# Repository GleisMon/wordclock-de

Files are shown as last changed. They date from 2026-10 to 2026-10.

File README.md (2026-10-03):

# Wortuhr – Firmware für die deutsche Word Clock (ESP8266)

Firmware für eine 3D-gedruckte Wortuhr mit deutschem Ziffernblatt (12 × 11 Buchstaben, 132 WS2812B-LEDs),
gesteuert von einem **Lolin NodeMCU v3 (ESP8266)**, der unsichtbar im Ständer sitzt.

[Русская версия](README.ru.md)

- Einrichtung ohne Programmieren: WLAN per Handy, Zeit per Internet (NTP), Sommerzeit automatisch
- Zufällige Farben – bei jeder neuen Anzeige bekommt **jedes** Wort eine neue Farbe
- Helligkeit, Nachtmodus, „MINUTEN“ ein/aus, Herz zur vollen Stunde (optional)
- Einstellungsseite im Browser: **http://wortuhr.local** (Deutsch / Русский / English)
- Updates über WLAN direkt aus GitHub Releases, signiert; Rettungsmodus falls etwas schiefgeht
- Strombegrenzung für ein 2-A-USB-Netzteil
- Optional: kleiner Bildschirm (0,91" OLED) im Ständer – zeigt Adresse, WLAN-Einrichtung, Fehler,
  Update-Fortschritt und auf Wunsch die genaue Uhrzeit

## Erste Inbetriebnahme

1. Uhr mit dem USB-C-Netzteil verbinden. Die vier Eck-LEDs pulsieren **blau**: die Uhr wartet auf WLAN-Daten.
2. Mit dem Handy das WLAN **„Wortuhr-Setup“** wählen. Die Einrichtungsseite öffnet sich (sonst `http://192.168.4.1`).
3. „Configure WiFi“ → eigenes WLAN wählen, Passwort eingeben, speichern.
4. Ecken pulsieren **orange**, bis die Uhrzeit aus dem Internet geholt ist – dann erscheint die Zeit.

Einstellungen danach im Browser unter **http://wortuhr.local** (oder über die IP-Adresse aus dem Router).

| Ecken pulsieren | Bedeutung |
|---|---|
| blau | Einrichtungs-WLAN „Wortuhr-Setup“ ist offen |
| orange | verbindet sich / wartet auf die Uhrzeit |
| rot | Rettungsmodus (siehe unten) |

Ist das WLAN 10 Minuten weg (z. B. neuer Router), öffnet die Uhr wieder „Wortuhr-Setup“ und zeigt
weiter die Zeit an.

## Wie die Zeit angezeigt wird

| Minute | Anzeige (Standard) |
|---|---|
| :00 | ES IST DREI UHR (bei 1 Uhr: ES IST EIN UHR) |
| :05 / :10 | ES IST FÜNF / ZEHN MINUTEN NACH DREI |
| :15 | ES IST VIERTEL NACH DREI |
| :20 | ES IST ZWANZIG MINUTEN NACH DREI *(oder: ZEHN VOR HALB VIER)* |
| :25 | ES IST FÜNF VOR HALB VIER |
| :30 | ES IST HALB VIER |
| :35 | ES IST FÜNF NACH HALB VIER |
| :40 | ES IST ZWANZIG MINUTEN VOR VIER *(oder: ZEHN NACH HALB VIER)* |
| :45 | ES IST VIERTEL VOR VIER |
| :50 / :55 | ES IST ZEHN / FÜNF MINUTEN VOR VIER |

„MINUTEN“ lässt sich abschalten, die Varianten für :20 / :40 und „ES IST nur zur vollen und halben Stunde“
stehen unter *Erweiterte Einstellungen*.

## Bildschirm im Ständer (optional)

Wird beim Start automatisch erkannt – ohne Bildschirm läuft dieselbe Firmware unverändert.

| Situation | Anzeige |
|---|---|
| WLAN-Einrichtung | „WLAN einrichten: Wortuhr-Setup · 192.168.4.1“ (solange das Portal offen ist) |
| nach dem Einschalten | IP-Adresse, wortuhr.local und Uhrzeit – für die eingestellte Zeit (Standard 5 min, 0 = aus, „immer“) |
| danach | aus (Standard) oder **genaue Uhrzeit** (gedimmt, wandert auf einer Acht-Bahn gegen Einbrennen: 1 Schritt/min, 1 Runde/h) |
| Fehler | „Kein WLAN“, „Keine Uhrzeit“, „Update fehlgeschlagen“ |
| Update | Fortschrittsbalken mit Prozent (GitHub, Browser-Upload, Arduino-OTA) |
| Nachtmodus | aus (Fehler werden gedimmt angezeigt) |

Einstellungen: *Bildschirm im Ständer* auf der Einstellungsseite (erscheint nur mit Bildschirm), dort auch „Bildschirm drehen“.

## Updates

Die Uhr schaut einmal am Tag nach, ob es auf GitHub eine neue Version gibt, und zeigt sie auf der
Einstellungsseite an („Update installieren“). Auf Wunsch installiert sie Updates nachts um 3 Uhr selbst.
Es werden nur Firmware-Dateien angenommen, die mit dem Schlüssel dieses Projekts signiert sind.

**Rettungsmodus:** Startet die Uhr dreimal hintereinander innerhalb von 30 Sekunden neu, öffnet sie das
WLAN **„Wortuhr-Rescue“** (Ecken rot). Dort unter `http://192.168.4.1/update` die Datei `wortuhr-de.bin`
aus dem neuesten [Release](https://github.com/GleisMon/wordclock-de/releases) hochladen.

## Hardware

| Teil | Hinweis |
|---|---|
| Gehäuse + Front | [`hardware/clock-case`](hardware/clock-case) – deutsches Layout von KS, Remix der Word Clock von johniak |
| Ständer | [`hardware/stand`](hardware/stand) – versteckt den NodeMCU, wird mit den zwei unteren Gehäuseschrauben befestigt (v4 ohne, v5 mit Bildschirmfenster) |
| Bildschirm (optional) | SSD1306 0,91" 128×32, I2C 0x3C: **SDA → D2 (GPIO4), SCL → D1 (GPIO5)**, VCC 3,3 V, GND |
| Controller | Lolin NodeMCU v3 (ESP8266, 4 MB Flash) |
| LEDs | WS2812B-Streifen 74 LED/m, 11 Reihen × 12, Schlangenlinie, Anfang unten rechts |
| Strom | 5 V / 2 A USB-Netzteil über USB-C-Einbaubuchse (nur Strom) |

Verdrahtung: LED **DIN → D4 (GPIO2)** über einen Widerstand (z. B. 330 Ω), LED 5 V und NodeMCU **VIN** direkt an
5 V der USB-C-Buchse, GND gemeinsam. Hinweis: Eine 2-polige USB-C-Buchse braucht 5,1-kΩ-CC-Widerstände,
sonst liefern C-auf-C-Netzteile keine Spannung.

## Entwicklung

Arduino-CLI, Board **NodeMCU 1.0 (ESP-12E)**, Flash-Layout **4MB (FS:1MB OTA:~1019KB)**:

```bash
arduino-cli core install esp8266:esp8266@3.1.2
arduino-cli lib install "NeoPixelBus by Makuna@2.8.4" "WiFiManager@2.0.17" "ArduinoJson@7.4.3" "U8g2@2.36.19"
arduino-cli compile --fqbn esp8266:esp8266:nodemcuv2:eesz=4M1M,xtal=160,ip=lm2f,ssl=all --output-dir build firmware/Wortuhr
```

- **Signatur:** `firmware/Wortuhr/public.key` ist eingebaut; die Firmware akzeptiert per OTA/Upload nur
  Images, die mit dem passenden `private.key` signiert sind. Der private Schlüssel liegt **nicht** im Repo
  (lokal neben dem Sketch, in CI als Secret `SIGNING_KEY`). Per USB lässt sich jede Firmware flashen.
- **Release:** `FW_VERSION` in `firmware/Wortuhr/version.h` erhöhen, committen, Tag `vX.Y.Z` pushen –
  GitHub Actions baut, signiert und veröffentlicht `wortuhr-de.bin` + `version.json`.
- **Serielle Konsole** (115200 Bd): `dump` gibt alle 144 Sätze für die aktuellen Einstellungen aus, `info` den Status.
- **Zertifikate:** Die Root-CAs für den GitHub-Download stehen in `certs.h`; erneuern mit `tools/make_certs.py`.

## Herkunft und Lizenzen

- **Word Clock** (Original, Gehäuse und Idee): [johniak – Word Clock auf MakerWorld](https://makerworld.com/en/models/686196),
  Code: [github.com/johniak/word-clock](https://github.com/johniak/word-clock)
- **Deutsche Version** (Gehäuse/Front mit deutschem Layout): [KS – Word Clock (German version) auf MakerWorld](https://makerworld.com/en/models/1222379),
  Lizenz **CC BY-SA 4.0** – die Datei in `hardware/clock-case` ist unverändert übernommen.
- **Ständer:** eigene Konstruktion, angelehnt an „Stand for Word Clock“ von **LarsIversen** (MakerWorld, CC BY-NC-SA) –
  daher ebenfalls **CC BY-NC-SA 4.0**.
- **Firmware** (`firmware/`, `tools/`): neu geschrieben, **MIT** (siehe [LICENSE](LICENSE)). Übernommen wurde nur
  die Buchstaben- und LED-Belegung der deutschen Front.

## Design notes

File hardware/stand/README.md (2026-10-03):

# Ständer mit verstecktem NodeMCU

> **Welche Datei?** Die Word Clock gibt es in zwei Größen. **v9** passt zur großen Version
> (`hardware/clock-case/word_clock_GERMAN_60LED_per_meter.3mf`, = 74-LED-Modell × 1,2333): Uhr 230,78 mm breit (Ständer genauso
> lang, bündig), Schraubenlöcher 213,5 mm auseinander, 8,63 mm über der Unterkante und vom Seitenrand; Uhrendicke gemessen 17,2 mm.
> **v4/v5** passen zur kleinen Version aus `hardware/clock-case` (74 LED/m): 187 mm breit, 15 mm dick, Löcher 173 mm.
> Vor dem Druck die eigene Uhr nachmessen und zuerst `wortuhr-stand_v9_testslice.stl` (22-mm-Endstück) anprobieren.

- `wortuhr-stand_v9.stl` / `.step` – große Uhr (60 LED/m), mit OLED-Fenster wie v5; Länge 230,78 mm (bündig mit der Uhr). USB-C-Ausschnitt rechteckig
  13,9 × 5,9 mm, symmetrisch (Buchse 14 × 5,2, in der Breite stramm; die runde 5,3-mm-Variante passte nicht), 2,5 mm tiefer als in v7 und weiter hinten, ganz über dem Schraubenblock (keine Aussparung im Block → keine
  Überhänge beim Druck mit dem Bildschirm nach unten); Übergang Boden → Auflage als gerade Fase 2 mm auf 6 mm; OLED-Tasche mit 2-mm-Rand innen
  (45°-Übergang in die Wand), Einstecktiefe 3,7 mm. Die STLs liegen für den Druck **Bildschirmseite nach unten**
  (schräge Rückwand auf dem Bett).
- `wortuhr-stand_v9_testslice.stl` – rechtes Endstück (Schraubenblock, USB-C-Buchse) zum Anprobieren.

- `wortuhr-stand_v5.stl` / `.step` – wie v4, zusätzlich Fenster für einen 0,91"-OLED (SSD1306 128×32) oben in der
  schrägen Rückwand: Tasche 39 × 12,2 × 1,7 mm von innen, Fenster 24 × 8,2 mm mit Fase 0,5 mm, 0,8 mm Haut,
  Wand überall 2,5 mm (kein Rahmen; das Modul steht innen ~0,8 mm über). Maße aus dem Reflex-Deckel.
  Modul mit einem Tropfen Kleber oder Klebeband sichern. Außerdem: keine Fasen an den Stirnkanten, die an der
  Uhr anliegen (Rückseite, Auflage, Vorderkante bündig mit der Front), 6-mm-Fase an der oberen Innenkante der
  Schraubenblöcke.
- `wortuhr-stand_v4.stl` – druckfertig, liegt so auf dem Druckbett, wie er auf dem Tisch steht (keine Stützen nötig)
- `wortuhr-stand_v4.step` – zum Weiterbearbeiten
- `fusion-scripts/` – Fusion-360-Skripte, die das Modell erzeugen (`v4_build.py`, `v5_chamfer.py`, `v5_screen.py`) und die Passung prüfen (`chk_v4.py`, `chk_v5.py`)

**Maße (v4/v5):** 194 × 50 × 56 mm; v9: 230,8 × 53 × 56 mm. Die Fusion-Skripte erzeugen v9 (Konstanten oben in `v4_build.py`), Uhr 10° nach hinten geneigt, Vorderseite bündig mit der Front der Uhr.

**Befestigung:** zwei Schrauben Ø 3,7 × 40 mm (Kopf Ø 5,9 × 2 mm) durch den Ständer in die beiden unteren
Löcher der Uhr. Klemmlänge 30 mm (Rückseite der Uhr bis Senkungsboden), Senkung Ø 6,6 × 2,5 mm,
Durchgang Ø 4,2 mm → die Schraube greift ca. 10 mm in den Dom der Uhr (verfügbar: 13 mm).
Unterlegscheibe M3 empfohlen.

**Innenraum:** NodeMCU v3 (58 × 31 mm) passt stehend hinter die Uhr. Rechts (von vorne) ein Ausschnitt
13,9 × 5,3 mm (abgerundet) für eine USB-C-Einbaubuchse 13,7 × 5,1 mm, Wand dort 1,5 mm für die Rastnasen.

Druck: PETG, 0,2 mm, Fasen 45° statt Rundungen.

**Lizenz:** CC BY-NC-SA 4.0 – angelehnt an „Stand for Word Clock“ von **LarsIversen** (MakerWorld, CC BY-NC-SA).
https://creativecommons.org/licenses/by-nc-sa/4.0/

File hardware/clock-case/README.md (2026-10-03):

# Gehäuse und Front – deutsches Layout

`word_clock_GERMAN_74LED_per_meter.3mf` – unverändert übernommen.

- **Word Clock (German version)** von **KS**: https://makerworld.com/en/models/1222379
- Remix von **Word Clock** von **johniak**: https://makerworld.com/en/models/686196
- Lizenz: **CC BY-SA 4.0** (Namensnennung, Weitergabe unter gleichen Bedingungen)
  https://creativecommons.org/licenses/by-sa/4.0/

Inhalt: Gehäuse (187 × 179 × 12 mm) mit transparenter und weißer Frontschicht, Rückplatte 3 mm
(Platte 2 im 3MF). Aufbauanleitung: https://github.com/johniak/word-clock/blob/main/docs/device_build.md

Zwei Größen, gleiche Lizenz (CC BY-SA 4.0, KS):
- `word_clock_GERMAN_74LED_per_meter.3mf` – 187 mm breit (74-LED/m-Streifen)
- `word_clock_GERMAN_60LED_per_meter.3mf` – dasselbe Modell × 1,2333 = 230,8 mm breit (60-LED/m-Streifen); dafür ist der Ständer v9.

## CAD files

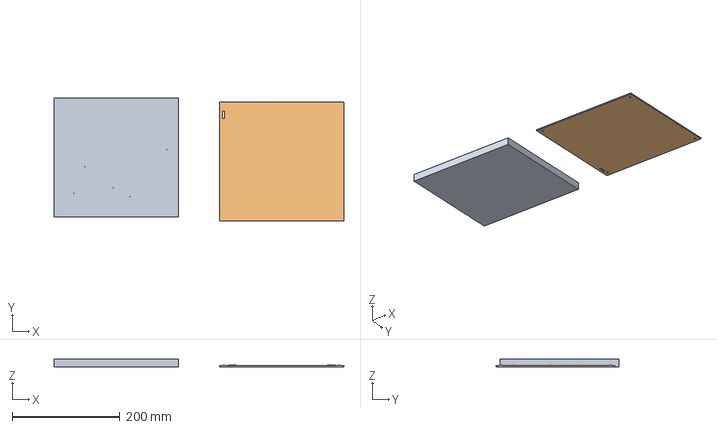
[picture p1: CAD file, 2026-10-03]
hardware/clock-case/word_clock_GERMAN_60LED_per_meter.3mf
537.3 x 227.8 x 14.8 mm
German box
obj_2_Body1.stl

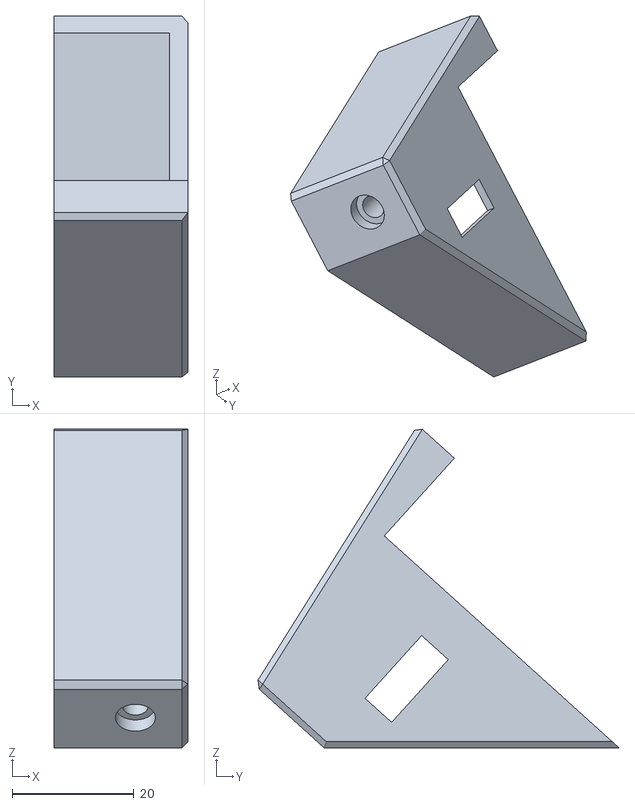
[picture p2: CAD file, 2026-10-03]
hardware/stand/wortuhr-stand_v9_testslice.stl
22.0 x 59.4 x 52.4

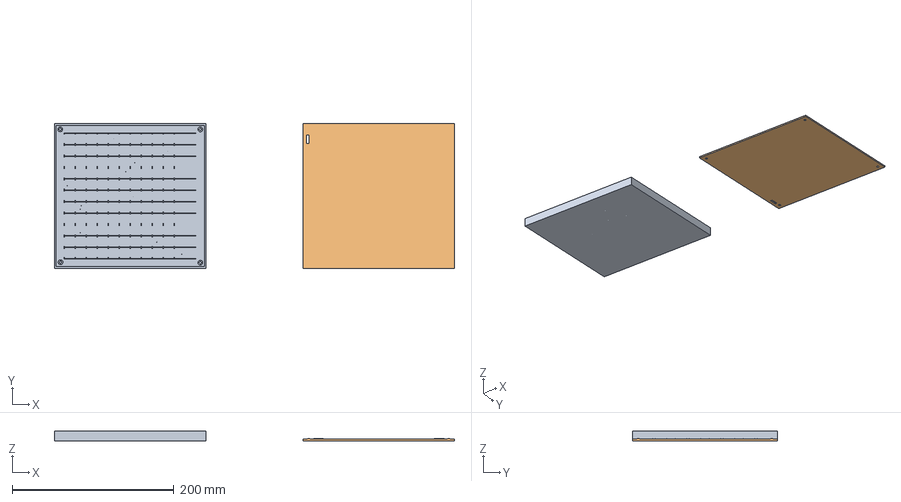
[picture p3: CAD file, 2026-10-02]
hardware/clock-case/word_clock_GERMAN_74LED_per_meter.3mf
494.3 x 178.6 x 12.0 mm
German box
obj_2_Body1.stl

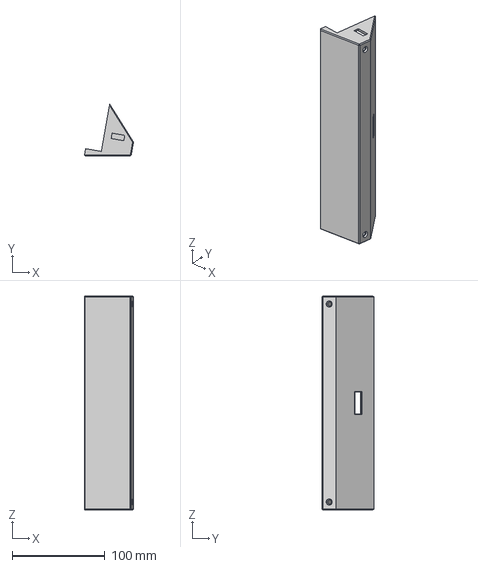
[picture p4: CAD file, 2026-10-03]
hardware/stand/wortuhr-stand_v9.step
53.0 x 56.2 x 230.8 mm

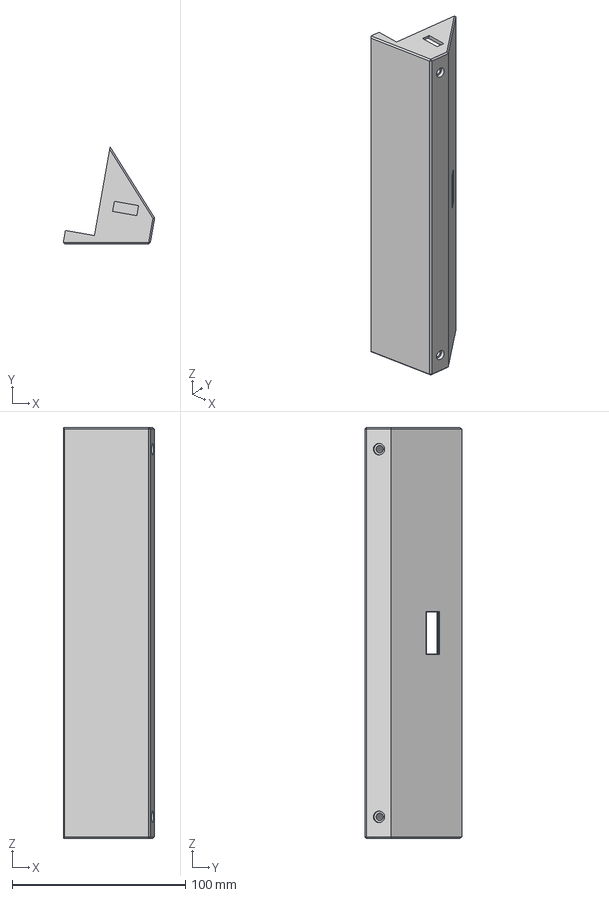
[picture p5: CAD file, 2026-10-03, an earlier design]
hardware/stand/wortuhr-stand_v8.step
52.8 x 56.2 x 237.0 mm

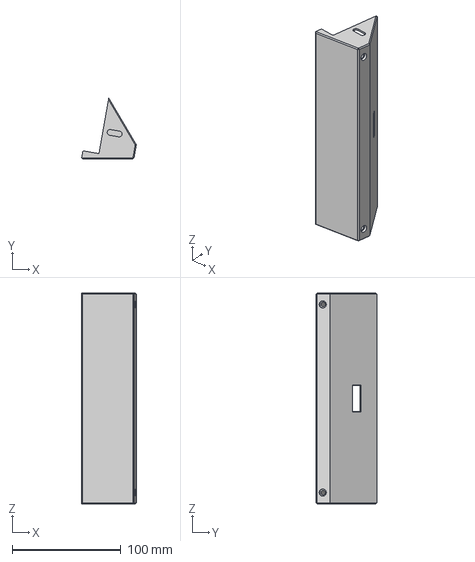
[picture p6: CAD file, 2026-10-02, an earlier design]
hardware/stand/wortuhr-stand_v5.step
50.4 x 56.2 x 194.1 mm

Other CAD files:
hardware/stand/wortuhr-stand_v6.step
hardware/stand/wortuhr-stand_v4.step
hardware/stand/wortuhr-stand_v4.stl
hardware/stand/wortuhr-stand_v5.stl
hardware/stand/wortuhr-stand_v9.stl

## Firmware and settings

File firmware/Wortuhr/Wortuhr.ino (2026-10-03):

// Wortuhr — German word clock firmware for ESP8266 (Lolin NodeMCU v3)
// https://github.com/GleisMon/wordclock-de
//
// LED data: D4 (GPIO2) through a series resistor. 132 x WS2812B, 12 x 11 grid.
#include <ESP8266WiFi.h>
#include <ESP8266WebServer.h>
#include <ESP8266HTTPUpdateServer.h>
#include <ESP8266mDNS.h>
#include <ArduinoOTA.h>
#include <WiFiManager.h>
#include <LittleFS.h>
#include <coredecls.h>
#include <time.h>

#include "version.h"
#include "grammar.h"
#include "display.h"
#include "settings.h"
#include "gh_update.h"
#include "webui.h"
#include "screen.h"

static const char *HOSTNAME = "wortuhr";
static const char *AP_SETUP = "Wortuhr-Setup";
static const char *AP_RESCUE = "Wortuhr-Rescue";
static const uint32_t PALETTE[] = {0xFF0000, 0x00FF00, 0x0000FF, 0xFFFF00, 0xFF00FF, 0x00FFFF, 0xFFFFFF, 0xFF7A00};
static const uint8_t PALETTE_N = sizeof(PALETTE) / sizeof(PALETTE[0]);

Display display;
Settings cfg;
GhUpdate gh;
ESP8266WebServer server(80);
ESP8266HTTPUpdateServer httpUpdater;
WiFiManager wm;
Screen screen;

enum Anim { A_NONE, A_HEART, A_TEST } anim = A_NONE;  // before the first function (Arduino prototypes)
uint32_t animStart = 0;

// ---------- texts for the optional stand display ----------
enum Txt { S_SETUP, S_WEB, S_NOWIFI, S_RETRY, S_NOTIME, S_RESCUE, S_UPDFAIL, S_UPDAVAIL, S_CONNECT, S_UPLOAD, S_RESTART, S_COUNT };
// one '\0'-separated block per language in flash (string constants would otherwise sit in RAM)
static const char TXT_DE[] PROGMEM =
  "WLAN einrichten:\0Einstellungen im Browser:\0Kein WLAN\0verbinde neu ...\0Keine Uhrzeit\0Rettungsmodus - WLAN:\0"
  "Update fehlgeschlagen\0Update verfügbar: \0verbinde ...\0Firmware-Upload\0Neustart ...";
static const char TXT_EN[] PROGMEM =
  "Set up WiFi:\0Settings in the browser:\0No WiFi\0reconnecting ...\0No time\0Rescue mode - WiFi:\0"
  "Update failed\0Update available: \0connecting ...\0Firmware upload\0restarting ...";
static const char TXT_RU[] PROGMEM =
  "Настройка Wi-Fi:\0Настройки в браузере:\0Нет Wi-Fi\0переподключение ...\0Нет времени\0Аварийный режим, Wi-Fi:\0"
  "Обновление не удалось\0Есть обновление: \0подключение ...\0Загрузка прошивки\0перезагрузка ...";
String T(Txt k) {
  const char *p = cfg.lang == "en" ? TXT_EN : cfg.lang == "ru" ? TXT_RU : TXT_DE;
  for (uint8_t i = 0; i < k; i++) p += strlen_P(p) + 1;
  return String(FPSTR(p));
}

bool rescue = false, routesReady = false, servicesUp = false, portalOn = false, otaReady = false;
uint32_t portalSince = 0, staRetryAt = 0, lostSince = 0, saveAt = 0, nextCheckAt = 0, rebootAt = 0, lastAutoTry = 0;
bool pendingCheck = false, pendingInstall = false, forceRecolor = true;
uint32_t lastMask = 0, lastTick = 0;
int lastHeartHour = -1;
uint32_t wordColor[W_COUNT];
RgbColor wordFrame[NUM_LEDS], frame[NUM_LEDS];


// ---------- rescue mode: 3 boots in a row that die within 30 s ----------
struct RtcBoot { uint32_t magic, count; };
static const uint32_t RTC_MAGIC = 0x57C10C01;
bool bootCounterCleared = false;

uint32_t bumpBootCounter() {
  RtcBoot b;
  ESP.rtcUserMemoryRead(0, (uint32_t *)&b, sizeof(b));
  if (b.magic != RTC_MAGIC) b = {RTC_MAGIC, 0};
  b.count++;
  ESP.rtcUserMemoryWrite(0, (uint32_t *)&b, sizeof(b));
  return b.count;
}
void clearBootCounter() {
  RtcBoot b = {RTC_MAGIC, 0};
  ESP.rtcUserMemoryWrite(0, (uint32_t *)&b, sizeof(b));
}

// ---------- update boot: the firmware download needs ~30 KB heap, so it runs in a reboot
// without web server / mDNS / OTA / portal. Request and result travel through RTC memory.
struct RtcText { uint32_t magic; char text[64]; };
static const uint32_t RTC_UPD_REQ = 0x55504451, RTC_UPD_RES = 0x55504452;
static const uint32_t RTC_OFS_REQ = 2, RTC_OFS_RES = 2 + sizeof(RtcText) / 4, RTC_OFS_CHK = 2 + 2 * sizeof(RtcText) / 4;
static const uint32_t RTC_CHECKING = 0x43484B31;  // set while a version check runs; survives a crash
bool autoCheckBlocked = false;

void rtcPut(uint32_t ofs, uint32_t magic, const String &s) {
  RtcText r = {magic, {0}};
  strncpy(r.text, s.c_str(), sizeof(r.text) - 1);
  ESP.rtcUserMemoryWrite(ofs, (uint32_t *)&r, sizeof(r));
}
bool rtcTake(uint32_t ofs, uint32_t magic, String &out) {
  RtcText r;
  ESP.rtcUserMemoryRead(ofs, (uint32_t *)&r, sizeof(r));
  if (r.magic != magic) return false;
  r.text[sizeof(r.text) - 1] = 0;
  out = r.text;
  r.magic = 0;
  ESP.rtcUserMemoryWrite(ofs, (uint32_t *)&r, sizeof(r));
  return true;
}

// ---------- helpers ----------
RgbColor rgb(uint32_t c) { return RgbColor((c >> 16) & 0xFF, (c >> 8) & 0xFF, c & 0xFF); }

uint8_t levelFromPct(uint8_t pct) {  // perceptual curve
  if (pct == 0) return 0;
  uint16_t v = (uint32_t)pct * pct * 255 / 10000;
  return v < 1 ? 1 : v;
}

bool inNight(int minuteOfDay) {
  if (!cfg.nightOn || cfg.nightFrom == cfg.nightTo) return false;
  return cfg.nightFrom < cfg.nightTo ? (minuteOfDay >= cfg.nightFrom && minuteOfDay < cfg.nightTo)
                                     : (minuteOfDay >= cfg.nightFrom || minuteOfDay < cfg.nightTo);
}

void fillCorners(RgbColor c) {
  for (uint16_t i = 0; i < NUM_LEDS; i++) frame[i] = RgbColor(0);
  frame[ledIndex(0, 0)] = frame[ledIndex(0, GRID_W - 1)] = frame[ledIndex(GRID_H - 1, 0)] = frame[ledIndex(GRID_H - 1, GRID_W - 1)] = c;
}

void statusPulse(uint32_t color) {  // corners breathe: blue = setup portal, orange = waiting for time, red = rescue
  float k = 0.15f + 0.85f * (0.5f + 0.5f * sinf(millis() / 600.0f));
  RgbColor c = rgb(color);
  fillCorners(RgbColor(c.R * k, c.G * k, c.B * k));
  display.setLevel(90);
  display.setFrame(frame);
}

void assignColors(const Phrase &p) {
  uint8_t idx[PALETTE_N];
  for (uint8_t i = 0; i < PALETTE_N; i++) idx[i] = i;
  for (uint8_t attempt = 0; attempt < 16; attempt++) {  // every word gets a new colour, all different
    for (int8_t i = PALETTE_N - 1; i > 0; i--) { uint8_t j = random(i + 1); uint8_t t = idx[i]; idx[i] = idx[j]; idx[j] = t; }
    bool ok = true;
    for (uint8_t i = 0; i < p.n; i++) if (wordColor[p.w[i]] == PALETTE[idx[i]]) { ok = false; break; }
    if (ok) break;
  }
  for (uint8_t i = 0; i < p.n; i++) wordColor[p.w[i]] = cfg.colorMode == 1 ? cfg.color : PALETTE[idx[i % PALETTE_N]];
}

void buildWordFrame(const Phrase &p) {
  for (uint16_t i = 0; i < NUM_LEDS; i++) wordFrame[i] = RgbColor(0);
  for (uint8_t i = 0; i < p.n; i++) {
    const WordPos &w = WORDS[p.w[i]];
    for (uint8_t c = 0; c < w.len; c++) wordFrame[ledIndex(w.row, w.col + c)] = rgb(wordColor[p.w[i]]);
  }
}

// ---------- animations ----------
static const char HEART[GRID_H][GRID_W + 1] = {
  "..XX....XX..", ".XXXX..XXXX.", "XXXXXXXXXXXX", "XXXXXXXXXXXX", "XXXXXXXXXXXX", ".XXXXXXXXXX.",
  "..XXXXXXXX..", "...XXXXXX...", "....XXXX....", ".....XX.....", "............"};

void startAnim(Anim a) { anim = a; animStart = millis(); }

bool renderAnim() {
  uint32_t t = millis() - animStart;
  if (anim == A_HEART) {
    if (t > 4000) return false;
    float ph = fmodf(t / 900.0f, 1.0f);  // lub-dub
    float beat = 0.35f + 0.65f * max(expf(-30 * ph * ph), 0.7f * expf(-30 * (ph - 0.28f) * (ph - 0.28f)));
    for (uint8_t r = 0; r < GRID_H; r++)
      for (uint8_t c = 0; c < GRID_W; c++)
        frame[ledIndex(r, c)] = HEART[r][c] == 'X' ? RgbColor(255 * beat, 0, 20 * beat) : RgbColor(0);
  } else if (anim == A_TEST) {
    if (t > 6000) return false;
    static const uint32_t seq[] = {0xFF0000, 0x00FF00, 0x0000FF, 0xFFFFFF};
    RgbColor c = rgb(seq[(t / 1500) % 4]);
    for (uint16_t i = 0; i < NUM_LEDS; i++) frame[i] = c;
  } else return false;
  display.setFrame(frame);
  return true;
}

// ---------- the clock ----------
void tick() {
  time_t now = time(nullptr);
  if (now < 1700000000) {  // no valid time yet
    statusPulse(portalOn ? 0x0040FF : 0xFF8000);
    return;
  }
  struct tm t;
  localtime_r(&now, &t);
  bool night = inNight(t.tm_hour * 60 + t.tm_min);
  display.setLevel(levelFromPct(night ? cfg.nightBrightness : cfg.brightness));

  if (lastHeartHour < 0) lastHeartHour = t.tm_hour;
  if (cfg.heart && t.tm_min == 0 && t.tm_hour != lastHeartHour && anim == A_NONE) {
    lastHeartHour = t.tm_hour;
    if (!(night && cfg.nightBrightness == 0)) startAnim(A_HEART);
  }
  if (anim != A_NONE) {
    if (renderAnim()) return;
    anim = A_NONE;
    display.setTarget(wordFrame, cfg.fade ? 600 : 0);
  }

  GrammarOpts o;
  o.minuten = cfg.minuten; o.v20 = cfg.v20; o.v40 = cfg.v40; o.esIstAlways = cfg.esIstAlways;
  Phrase p = buildPhrase(t.tm_hour, t.tm_min, o);
  if (p.mask != lastMask || forceRecolor) {
    assignColors(p);
    buildWordFrame(p);
    display.setTarget(wordFrame, cfg.fade ? 900 : 0);
    lastMask = p.mask;
    forceRecolor = false;
  }
}

// ---------- stand display: what to show, most important first ----------
void screenLoop() {
  if (!screen.present) return;
  // screens that can stay up for long drift on the burn-in orbit (see Screen::orbit)
  if (rescue) { screen.text(T(S_RESCUE), AP_RESCUE, "192.168.4.1/update", 160, true); return; }
  if (portalOn) { screen.text(T(S_SETUP), AP_SETUP, "192.168.4.1", 160, true); return; }
  time_t now = time(nullptr);
  bool valid = now > 1700000000, up = WiFi.status() == WL_CONNECTED;
  struct tm t = {};
  if (valid) localtime_r(&now, &t);
  bool night = valid && inNight(t.tm_hour * 60 + t.tm_min);
  if (!up && lostSince && millis() - lostSince > 20000) { screen.text(T(S_NOWIFI), WiFi.SSID(), T(S_RETRY), night ? 12 : 160, true); return; }
  if (up && !valid && millis() > 60000) { screen.text(T(S_NOTIME), "NTP", cfg.ntp, night ? 12 : 160, true); return; }
  bool always = cfg.oledMin == 255;
  bool infoTime = always || millis() < cfg.oledMin * 60000UL;
  if (valid && t.tm_min == 0 && t.tm_sec < 2 && (always || cfg.oledAfter == 1)) { screen.off(); return; }  // 2 s rest each hour
  if (infoTime && !night) {
    String foot = "wortuhr.local";
    if (gh.error.startsWith("Update")) foot = T(S_UPDFAIL);
    else if (gh.available()) foot = T(S_UPDAVAIL) + gh.latest;
    else if (valid) { char b[8]; snprintf(b, sizeof(b), "  %02d:%02d", t.tm_hour, t.tm_min); foot += b; }
    screen.text(T(S_WEB), up ? WiFi.localIP().toString() : T(S_CONNECT), foot, 160, always);
    return;
  }
  if (cfg.oledAfter == 1 && valid && !night) { screen.clock(t.tm_hour, t.tm_min); return; }
  screen.off();
}

// ---------- web ----------
void applyConfig(const Settings &old) {
  screen.setFlip(cfg.oledFlip);
  screen.setLang(cfg.lang);
  display.setLimit(cfg.limitMa);
  if (old.tz != cfg.tz || old.ntp != cfg.ntp) configTime(cfg.tz.c_str(), cfg.ntp.c_str(), "pool.ntp.org");
  if (old.colorMode != cfg.colorMode || (cfg.colorMode == 1 && old.color != cfg.color)) forceRecolor = true;
}

void handleState() {
  JsonDocument doc;
  cfg.toJson(doc["cfg"].to<JsonObject>());
  JsonObject st = doc["st"].to<JsonObject>();
  time_t now = time(nullptr);
  st["synced"] = now > 1700000000;
  if (now > 1700000000) {
    struct tm t; localtime_r(&now, &t);
    char b[24];
    strftime(b, sizeof(b), "%H:%M", &t); st["time"] = b;
    strftime(b, sizeof(b), "%d.%m.%Y", &t); st["date"] = b;
  }
  st["ver"] = FW_VERSION;
  st["ip"] = WiFi.localIP().toString();
  st["ssid"] = WiFi.SSID();
  st["rssi"] = WiFi.RSSI();
  st["heap"] = ESP.getFreeHeap();
  st["uptime"] = millis() / 1000;
  st["mA"] = display.lastMa();
  st["checked"] = gh.checked;
  st["latest"] = gh.latest;
  st["updAvail"] = gh.available();
  st["updErr"] = gh.error;
  st["updHeap"] = gh.heapAtConnect;
  st["updBlock"] = gh.blockAtConnect;
  st["oled"] = screen.present;
  String out;
  serializeJson(doc, out);
  server.send(200, "application/json", out);
}

void handleConfig() {
  JsonDocument doc;
  if (deserializeJson(doc, server.arg("plain"))) { server.send(400, "text/plain", "bad json"); return; }
  Settings old = cfg;
  cfg.fromJson(doc.as<JsonObjectConst>());
  applyConfig(old);
  saveAt = millis() + 3000;  // sliders: write flash once they stop moving
  server.send(200, "application/json", "{\"ok\":true}");
}

void handleAction() {
  String a = server.arg("a");
  if (a == "reroll") forceRecolor = true;
  else if (a == "heartnow") startAnim(A_HEART);
  else if (a == "test") startAnim(A_TEST);
  else if (a == "check") pendingCheck = true;
  else if (a == "install") pendingInstall = true;
  else if (a == "reboot") rebootAt = millis() + 500;
  else if (a == "wifireset") { wm.resetSettings(); rebootAt = millis() + 500; }
  else if (a == "factory") { LittleFS.remove("/config.json"); wm.resetSettings(); rebootAt = millis() + 500; }
  else { server.send(400, "text/plain", "unknown action"); return; }
  server.send(200, "application/json", "{\"ok\":true}");
}

void setupRoutes() {
  if (routesReady) return;
  if (rescue) {
    server.on("/", HTTP_GET, [] { server.send_P(200, "text/html", RESCUE_HTML); });
    server.on("/normal", HTTP_GET, [] { clearBootCounter(); server.send(200, "text/plain", "Neustart..."); rebootAt = millis() + 500; });
  } else {
    server.on("/", HTTP_GET, [] { server.send_P(200, "text/html", INDEX_HTML); });
    server.on("/api/state", HTTP_GET, handleState);
    server.on("/api/config", HTTP_POST, handleConfig);
    server.on("/api/action", HTTP_POST, handleAction);
  }
  httpUpdater.setup(&server, "/update");  // Updater only accepts images signed with our key
  server.onNotFound([] { server.sendHeader("Location", "/"); server.send(302); });
  routesReady = true;
}

void startServices() {
  setupRoutes();
  server.begin();
  MDNS.begin(HOSTNAME);
  MDNS.addService("http", "tcp", 80);
  if (!otaReady) {
    ArduinoOTA.setHostname(HOSTNAME);
    ArduinoOTA.onProgress([](unsigned int done, unsigned int total) { uploadProgress(done, total); });
    ArduinoOTA.begin();
    otaReady = true;
  }
  servicesUp = true;
  if (!nextCheckAt) nextCheckAt = millis() + 60000;
  Serial.printf("[net] %s  http://%s.local  ip %s\n", WiFi.SSID().c_str(), HOSTNAME, WiFi.localIP().toString().c_str());
}

void stopServices() {
  server.stop();
  MDNS.end();
  servicesUp = false;
}

void openPortal() {
  if (servicesUp) stopServices();
  wm.startConfigPortal(rescue ? AP_RESCUE : AP_SETUP);
  portalOn = true;
  portalSince = millis();
  Serial.println("[net] setup portal open");
}

// ---------- WiFi state machine ----------
void wifiLoop() {
  if (portalOn) wm.process();
  bool up = WiFi.status() == WL_CONNECTED;
  if (up) {
    lostSince = 0; staRetryAt = 0;
    if (portalOn) { wm.stopConfigPortal(); portalOn = false; }
    if (!servicesUp) startServices();
    return;
  }
  if (!lostSince) lostSince = millis();
  if (portalOn) {
    // saved network may be back: every 5 min (nobody on the portal) try it for 30 s
    if (millis() - portalSince > 300000 && wm.getWiFiIsSaved() && WiFi.softAPgetStationNum() == 0) {
      wm.stopConfigPortal(); portalOn = false;
      WiFi.mode(WIFI_STA); WiFi.begin();
      staRetryAt = millis();
    }
  } else if (staRetryAt && millis() - staRetryAt > 30000) {
    staRetryAt = 0; openPortal();
  } else if (!staRetryAt && millis() - lostSince > 600000) {
    openPortal();  // lost for 10 min (new router?) -> offer setup again, keep showing time
  }
}

void installUpdate() {  // normal mode: hand over to the update boot
  if (!gh.available()) return;
  MDNS.end();
  String url;
  bool ok = gh.assetUrl(url);  // follow github.com's redirects here, the update boot only talks to the CDN
  MDNS.begin(HOSTNAME);
  MDNS.addService("http", "tcp", 80);
  if (!ok) { Serial.printf("[upd] resolve failed: %s\n", gh.error.c_str()); return; }
  File f = LittleFS.open("/upd.url", "w");
  if (!f) { gh.error = "fs"; return; }
  f.print(url);
  f.close();
  Serial.printf("[upd] rebooting to install %s\n", gh.latest.c_str());
  screen.text("Update " + gh.latest, T(S_RESTART), "");
  if (saveAt) cfg.save();
  rtcPut(RTC_OFS_REQ, RTC_UPD_REQ, gh.latest);
  delay(50);
  ESP.restart();
}

void ledProgress(int done, int total) {
  fillCorners(RgbColor(0));
  for (uint16_t i = 0; i < (uint32_t)NUM_LEDS * done / max(total, 1); i++) frame[i] = RgbColor(0, 0, 255);
  display.setLevel(60); display.setFrame(frame); display.loop();
}

void uploadProgress(size_t done, size_t total) {  // web upload / ArduinoOTA
  ledProgress(done, total);
  screen.progress(T(S_UPLOAD), done, total);
}

void showProgress(int done, int total) {  // GitHub update (update boot)
  ledProgress(done, total);
  screen.progress("Update " + gh.latest, done, total);
}

void runUpdateBoot(const String &version) {
  clearBootCounter();  // a deliberate reboot, not a crash
  Serial.printf("[upd] update boot -> %s\n", version.c_str());
  String url;
  if (LittleFS.begin()) {
    File f = LittleFS.open("/upd.url", "r");
    if (f) { url = f.readString(); f.close(); }
    LittleFS.remove("/upd.url");
    cfg.load();  // display orientation and language only
    LittleFS.end();  // give its buffers back before TLS
  }
  display.begin();
  gh.latest = version;
  screen.begin(cfg.oledFlip);
  screen.setLang(cfg.lang);
  screen.text("Update " + version, T(S_CONNECT), "");
  ledProgress(0, 1);
  WiFi.mode(WIFI_STA);
  WiFi.begin();  // credentials saved by WiFiManager
  uint32_t t0 = millis();
  while (WiFi.status() != WL_CONNECTED && millis() - t0 < 40000) { delay(100); statusPulse(0x0040FF); display.loop(); }
  configTime(TZ_BERLIN, "de.pool.ntp.org", "pool.ntp.org");
  t0 = millis();
  while (time(nullptr) < 1700000000 && millis() - t0 < 30000) { delay(100); statusPulse(0x0040FF); display.loop(); }
  gh.latest = version;
  if (!url.startsWith("https://")) gh.error = "no URL";
  else if (WiFi.status() != WL_CONNECTED) gh.error = "no WiFi";
  else {
    Serial.printf("[upd] heap before download %u (max block %u)\n", ESP.getFreeHeap(), ESP.getMaxFreeBlockSize());
    gh.install(url, showProgress);  // reboots on success
  }
  Serial.printf("[upd] failed: %s heap@connect=%u block=%u\n", gh.error.c_str(), gh.heapAtConnect, gh.blockAtConnect);
  rtcPut(RTC_OFS_RES, RTC_UPD_RES, gh.error);
  delay(50);
  ESP.restart();
}

// ---------- serial console: "dump" prints every phrase for the current options ----------
void serialConsole() {
  static String line;
  while (Serial.available()) {
    char ch = Serial.read();
    if (ch != '\n' && ch != '\r') { if (line.length() < 32) line += ch; continue; }
    if (line == "dump") {
      GrammarOpts o;
      o.minuten = cfg.minuten; o.v20 = cfg.v20; o.v40 = cfg.v40; o.esIstAlways = cfg.esIstAlways;
      for (int h = 0; h < 24; h++)
        for (int m = 0; m < 60; m += 5) {
          Phrase p = buildPhrase(h, m, o);
          Serial.printf("%02d:%02d", h, m);
          for (uint8_t i = 0; i < p.n; i++) Serial.printf(" %s", WORD_NAMES[p.w[i]]);
          Serial.println();
          yield();
        }
      Serial.println("END");
    } else if (line == "info") {
      Serial.printf("%s %s heap=%u mA=%u ip=%s\n", FW_NAME, FW_VERSION, ESP.getFreeHeap(), display.lastMa(), WiFi.localIP().toString().c_str());
    }
    line = "";
  }
}
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
void loop() {
  if (!bootCounterCleared && millis() > 30000) { clearBootCounter(); bootCounterCleared = true; }
  if (rebootAt && millis() > rebootAt) ESP.restart();

  if (rescue) {
    server.handleClient();
    MDNS.update();
    if (millis() - lastTick > 30) { lastTick = millis(); statusPulse(0xFF0000); screenLoop(); }
    display.loop();
    return;
  }

  serialConsole();
  wifiLoop();
  if (servicesUp) { server.handleClient(); MDNS.update(); ArduinoOTA.handle(); }

  if (saveAt && millis() > saveAt) { cfg.save(); saveAt = 0; }

  if (servicesUp && (pendingCheck || (!autoCheckBlocked && nextCheckAt && millis() > nextCheckAt))) {
    pendingCheck = false;
    nextCheckAt = millis() + 24UL * 3600 * 1000;
    MDNS.end();  // TLS needs every free byte
    rtcPut(RTC_OFS_CHK, RTC_CHECKING, "");
    gh.check();
    String dummy; rtcTake(RTC_OFS_CHK, RTC_CHECKING, dummy);
    MDNS.begin(HOSTNAME);
    MDNS.addService("http", "tcp", 80);
    Serial.printf("[upd] latest=%s err=%s heap@connect=%u block=%u heap=%u\n", gh.latest.c_str(), gh.error.c_str(), gh.heapAtConnect, gh.blockAtConnect, ESP.getFreeHeap());
  }
  if (servicesUp && pendingInstall) { pendingInstall = false; installUpdate(); }
  if (servicesUp && cfg.autoUpdate && gh.available() && millis() - lastAutoTry > 3600000UL) {
    time_t now = time(nullptr); struct tm t; localtime_r(&now, &t);
    if (t.tm_hour == 3) { lastAutoTry = millis(); installUpdate(); }
  }

  if (millis() - lastTick > 30) { lastTick = millis(); tick(); }
  static uint32_t lastScreen = 0;
  if (millis() - lastScreen > 250) { lastScreen = millis(); screenLoop(); }
  display.loop();
}

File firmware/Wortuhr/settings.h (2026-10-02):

#pragma once
// User settings, persisted as /config.json on LittleFS.
#include <LittleFS.h>
#include <ArduinoJson.h>

#define TZ_BERLIN "CET-1CEST,M3.5.0,M10.5.0/3"

struct Settings {
  uint8_t brightness = 60;        // %
  bool nightOn = false;
  uint16_t nightFrom = 22 * 60;   // minutes after midnight
  uint16_t nightTo = 7 * 60;
  uint8_t nightBrightness = 10;   // %, 0 = display off
  bool minuten = true;
  uint8_t v20 = 0, v40 = 0;
  bool esIstAlways = true;
  bool heart = false;             // heart animation at every full hour
  uint8_t colorMode = 0;          // 0 = random colours per word, 1 = single colour
  uint32_t color = 0xFFB060;      // single colour (warm white)
  bool fade = true;
  String tz = TZ_BERLIN;
  String ntp = "de.pool.ntp.org";
  uint16_t limitMa = 1500;        // LED current budget (2 A supply - ESP8266 reserve)
  bool autoUpdate = false;
  String lang = "de";             // web UI language
  uint8_t oledMin = 5;            // stand display: minutes on after power-up (0 = off, 255 = always)
  uint8_t oledAfter = 0;          // after that: 0 = off, 1 = exact time
  bool oledFlip = false;          // module mounted the other way round

  void toJson(JsonObject o) const {
    o["brightness"] = brightness; o["nightOn"] = nightOn; o["nightFrom"] = nightFrom; o["nightTo"] = nightTo;
    o["nightBrightness"] = nightBrightness; o["minuten"] = minuten; o["v20"] = v20; o["v40"] = v40;
    o["esIstAlways"] = esIstAlways; o["heart"] = heart; o["colorMode"] = colorMode; o["color"] = color;
    o["fade"] = fade; o["tz"] = tz; o["ntp"] = ntp; o["limitMa"] = limitMa; o["autoUpdate"] = autoUpdate; o["lang"] = lang;
    o["oledMin"] = oledMin; o["oledAfter"] = oledAfter; o["oledFlip"] = oledFlip;
  }

  void fromJson(JsonObjectConst o) {
    brightness = constrain((int)(o["brightness"] | brightness), 1, 100);
    nightOn = o["nightOn"] | nightOn;
    nightFrom = (uint16_t)(o["nightFrom"] | nightFrom) % 1440;
    nightTo = (uint16_t)(o["nightTo"] | nightTo) % 1440;
    nightBrightness = constrain((int)(o["nightBrightness"] | nightBrightness), 0, 100);
    minuten = o["minuten"] | minuten;
    v20 = (o["v20"] | v20) ? 1 : 0;
    v40 = (o["v40"] | v40) ? 1 : 0;
    esIstAlways = o["esIstAlways"] | esIstAlways;
    heart = o["heart"] | heart;
    colorMode = (o["colorMode"] | colorMode) ? 1 : 0;
    color = (o["color"] | color) & 0xFFFFFF;
    fade = o["fade"] | fade;
    if (o["tz"].is<const char *>() && strlen(o["tz"]) > 0 && strlen(o["tz"]) < 60) tz = o["tz"].as<const char *>();
    if (o["ntp"].is<const char *>() && strlen(o["ntp"]) > 0 && strlen(o["ntp"]) < 60) ntp = o["ntp"].as<const char *>();
    limitMa = constrain((int)(o["limitMa"] | limitMa), 300, 3000);
    autoUpdate = o["autoUpdate"] | autoUpdate;
    int om = o["oledMin"] | (int)oledMin;
    oledMin = om >= 255 ? 255 : constrain(om, 0, 60);
    oledAfter = (o["oledAfter"] | oledAfter) ? 1 : 0;
    oledFlip = o["oledFlip"] | oledFlip;
    if (o["lang"].is<const char *>()) { String l = o["lang"].as<const char *>(); if (l == "de" || l == "ru" || l == "en") lang = l; }
  }

  void load() {
    File f = LittleFS.open("/config.json", "r");
    if (!f) return;
    JsonDocument doc;
    if (!deserializeJson(doc, f)) fromJson(doc.as<JsonObjectConst>());
    f.close();
  }

  void save() const {
    File f = LittleFS.open("/config.json", "w");
    if (!f) return;
    JsonDocument doc;
    toJson(doc.to<JsonObject>());
    serializeJson(doc, f);
    f.close();
  }
};

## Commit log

2026-10-02 Wortuhr firmware 0.1.0, clock case and stand
    - ESP8266 (Lolin NodeMCU v3) firmware for the German 12x11 word clock:
    WiFiManager setup portal, NTP with POSIX TZ (DST), random per-word colours
    re-rolled on every change, brightness/night mode, current limit,
    web UI (DE/RU/EN), signed OTA from GitHub Releases with verified TLS,
    rescue mode after 3 failed boots, serial "dump" for grammar checks
    - hardware/clock-case: German layout by KS (CC BY-SA 4.0), unchanged
    - hardware/stand: stand hiding the NodeMCU, fixed with two screws into the
    clock's lower holes (CC BY-NC-SA 4.0, after LarsIversen's stand)
    - CI: build on push, signed release on vX.Y.Z tags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
    [word_clock_GERMAN_74LED_per_meter.3mf, wortuhr-stand_v4.step, wortuhr-stand_v4.stl]
2026-10-02 Updates: fit TLS into ESP8266 heap, install in a lean update boot
    - version check uses an 8 KB TLS receive buffer (GitHub handshake records
    are <= ~4 KB, no MFLN support)
    - firmware download reboots into an update boot without web server, mDNS,
    OTA or portal so the 16 KB-record TLS session fits; request/result are
    passed through RTC memory and shown in the web UI
    - root CAs trimmed to USERTrust ECC, Sectigo E46, ISRG X1
    - TLS error codes and heap at connect in the status
    [Wortuhr.ino]
2026-10-02 Fix soft-WDT reset during the update check, 160 MHz
    The asset CDN chains to ISRG Root X1 (RSA-4096); verifying it took longer
    than the 3 s soft watchdog at 80 MHz and rebooted the clock about a minute
    after every start. Now: CPU at 160 MHz, soft WDT paused around the TLS
    handshake (HW WDT stays armed), and a crash inside a check is remembered
    in RTC memory so the next boot skips the automatic check.
    [Wortuhr.ino]
2026-10-02 Updates that fit the ESP8266 heap: resolve redirects first, then one CDN session
    - github.com redirects (latest -> tag -> CDN) are followed in normal mode with
    8 KB buffers; the short-lived CDN URL is stored in LittleFS
    - the update boot opens a single TLS session to the CDN on an unfragmented
    heap (needs one 16.7 KB block); root CAs split per host, CDN gets ISRG X1 only
    - status shows heap and largest free block at connect
    Tested on the clock: 0.1.1 -> 0.1.2 installed from GitHub Releases in 55 s.
    [Wortuhr.ino]
2026-10-02 Optional stand display (0.91" SSD1306) and stand v5
    Firmware 0.1.4:
    - SSD1306 128x32 on D2/D1 detected at start-up; same firmware without it
    - shows the setup AP, IP/wortuhr.local for a configurable time after
    power-up (default 5 min, 0 = off, always), then off or the exact time
    (dimmed, drifting against burn-in); errors (no WiFi / no time / update
    failed) and progress bars for GitHub, browser and ArduinoOTA updates
    - web UI card "Bildschirm im Ständer" (only with a display), rotate option
    - page-mode U8g2 and PROGMEM texts to keep the heap for TLS
    Stand v5: OLED pocket and window in the sloped rear wall (Reflex lid
    dimensions), wall flush at 2.5 mm; no chamfers on edges touching the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
    [wortuhr-stand_v5.step, wortuhr-stand_v5.stl]
2026-10-03 Stand v6 for the large (60 LED/m) clock: 230 wide, 17 thick, holes 213/8
    v4/v5 were built from the 74 LED/m 3MF (187 mm) - the real clock is the
    60 LED/m version. Parameters now in v4_build.py: CLOCK_W 230, CLOCK_T 17,
    holes 213 apart at 8 mm, screw blocks 14 mm high; fit checks follow the
    parameters. Adds a 22 mm test slice to try the fit before the full print.
    [wortuhr-stand_v6.step, wortuhr-stand_v6.stl, wortuhr-stand_v6_testslice.stl]
2026-10-03 Stand v7: holes 212 apart, 9 mm up (re-measured with a precise rule)
    Screw blocks raised to 15 mm (counterbore top now at 12.3 mm). v6 files
    removed (wrong hole positions by 0.5/1 mm); git history keeps them.
    [wortuhr-stand_v6.stl, wortuhr-stand_v6_testslice.stl, wortuhr-stand_v7.step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]
2026-10-03 Fit check: measured LED wire slot (5.5 mm from the side, 16.6 mm up) - clear of the screw blocks (top 15 mm)
2026-10-03 Stand v8: USB-C cutout that fits, smooth floor-to-seat transition
    - USB-C panel socket: rectangular 13.9 x 5.8 (the 13.9 x 5.3 stadium did not
    fit on the test print), centre moved down/back away from the clock's LED
    wire exit; bay in the +z screw block for the socket body and clips
    - 2 mm vertical step from the cavity floor to the clock seat replaced by an
    R5 arc tangent to the floor (printing)
    - fit checks: socket body, clip room, LED wire corridor at the socket end
    [wortuhr-stand_v7.step, wortuhr-stand_v7.stl, wortuhr-stand_v7_testslice.stl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]
2026-10-03 Stand v8: 2 mm rim around the OLED pocket, USB-C cutout roof, STL for OLED-down printing
    - inner rim 2 mm above the wall around the OLED pocket (fit test: the 1.7 mm
    pocket held too little), 45 deg outer flank into the wall; insertion depth 3.7 mm
    - printed with the sloped rear wall on the bed, the USB-C cutout gets a 50 deg
    triangular roof (kept inside the socket flange)
    - STLs exported in that print orientation; rim profile picked by area
    [wortuhr-stand_v8.step, wortuhr-stand_v8.stl, wortuhr-stand_v8_testslice.stl]
2026-10-03 Stand v8: USB-C socket above the screw block again, no recess in the block
    The recess cut into the +z screw block for the lowered socket left
    overhanging faces when printing OLED-side down. Socket centre now u=18.5
    (body bottom 15.6 above the block top 15), n=15; panel thinning only above
    the block (7 mm tall). Block under the socket is solid again.
    [wortuhr-stand_v8.step, wortuhr-stand_v8.stl, wortuhr-stand_v8_testslice.stl]
2026-10-03 Stand v8: symmetric USB-C cutout 14.2 x 5.9 for the 14 x 5.2 socket
    Triangular roof removed (it made the cutout asymmetric); ROOF_DEG = 0 keeps
    the code for later. Fit check uses the measured 14 x 5.2 socket body.
    [wortuhr-stand_v8.step, wortuhr-stand_v8.stl, wortuhr-stand_v8_testslice.stl]
2026-10-03 Stand v8: floor-to-seat transition as a straight 2-over-6 mm ramp
    The R5 arc (4 mm long) was too abrupt; now a chamfer-like ramp 50 % longer.
    Saved Fusion document "Wortuhr Staender v8" got the same change (join of the
    difference, volume identical to a fresh build: 103.937 cm3).
    [wortuhr-stand_v8.step, wortuhr-stand_v8.stl, wortuhr-stand_v8_testslice.stl]
2026-10-03 Stand v9 from the 60 LED/m clock model: flush length, holes per model
    word_clock_GERMAN_60LED_per_meter.3mf is the 74 LED/m model scaled 1.2333.
    - stand length = clock width 230.78 (ends flush, end walls inside), was 237
    - screw holes +-106.76 (213.5 apart), 8.63 above the bottom edge and from
    the side, per model (were 212 / 9 from hand measurements)
    - clock thickness 17.2 (measured on the printed clock)
    - adds the 60 LED/m clock 3MF to hardware/clock-case (CC BY-SA, KS)
    [word_clock_GERMAN_60LED_per_meter.3mf, wortuhr-stand_v8.stl, wortuhr-stand_v8_testslice.stl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]
2026-10-03 Stand README: v9 header (60 LED/m model, flush, holes 213.5 / 8.63)
2026-10-03 Stand v9: USB-C cutout width 14.2 -> 13.9 (fit test)
    [wortuhr-stand_v9.step, wortuhr-stand_v9.stl, wortuhr-stand_v9_testslice.stl]
2026-10-03 Firmware 0.1.5: OLED burn-in protection
    - exact-time screen: smooth figure-eight orbit (+-18 px, +-3 px), one step
    per minute, one lap per hour, instead of 24-px jumps every 5 minutes
    - long-running text screens (setup portal, rescue, errors, "always on")
    drift +-3 px / 1 px on the same orbit
    - "always on" / exact time: display off for 2 s at every full hour
    [Wortuhr.ino]
2026-10-12 Stand v10: 1 mm chamfers on the remaining sharp outer edges
2026-10-12 Clock case 60 LED/m: chamfered variant (all outer edges) + script
2026-10-12 Stand v11 and case back plate for 4.7 mm stand screws
